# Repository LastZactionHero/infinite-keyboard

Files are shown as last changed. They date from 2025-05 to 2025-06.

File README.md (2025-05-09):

Infinite Keyboard is a portable musical scratchpad. It continously captures of every note played on the integrated keyboard as MIDI data, saved directly to an SD card. This allows you to freely play ideas as they occur, knowing they can always revisit the performance later. The system uses an ESP32-S3 microcontroller, with aPCM5102 DAC and TPA6130A2 headphone amplifier, and supports USB connectivity for potential MIDI output or other functions.

1. ESP32-S3 Module (ESP32-S3-WROOM-1-N8)
    [ ] Power (3.3V):
        [X] Connect module Pin 2 (3V3) to the main 3.3V power rail.
        [X] Connect module Pin 1 and Pin 40 (GND) and EPAD (Pin 41) to the main ground plane.
        [ ] Place bulk decoupling capacitor (10µF - 22µF) near the module between 3.3V and GND.
        [ ] Place local decoupling capacitor (0.1µF - 1µF) very close to Pin 2 (3V3) and GND.
    [X] Enable/Reset Circuit:
        [X] Connect an RC delay circuit to the EN pin (Pin 3): 10kΩ resistor to 3.3V, 1µF capacitor to GND.
        [X] Connect a momentary push button (Reset Switch) between EN (Pin 3) and GND.
    [X] Boot Mode Circuit:
        [X] Connect a 10kΩ pull-up resistor from GPIO0 (Pin 27) to 3.3V.
        [X] Connect a momentary push button (Boot Switch) between GPIO0 (Pin 27) and GND.
    [X] Crystal Oscillator: 40 MHz crystal is integrated within the module. No external crystal needed.
    [X] Antenna: Use onboard PCB antenna (WROOM-1). Ensure proper keep-out zones on your PCB as per layout guidelines. [cite: uploaded:esp32_s3_wroom_1_wroom_1u_datasheet_en-2930317.pdf]
2. USB Interface (Native OTG)
    [-] Connections:
        [X] Connect ESP32-S3 GPIO19 (Module Pin 13) to USB Connector D-.
        [X] Connect ESP32-S3 GPIO20 (Module Pin 14) to USB Connector D+.
        [X] Connect USB Connector VBUS to 5V supply (if host mode power required, consider power switching).
        [X] Connect USB Connector GND to main ground.
        [-] Connect USB Connector Shield to main ground.
    [-] Optional Components:
        [X] Place 0Ω series resistors/jumpers on D+/D- lines if desired.
        [-] Place ESD protection diodes (TVS array) near the connector on D+/D- lines.
    [] Layout: Route D+/D- as a 90Ω differential pair.
3. I2S Interface (ESP32-S3 to PCM5102)
    [X] Connections:
        [X] Connect ESP32-S3 GPIO (Select Pin) -> PCM5102 BCK (Pin 13).
        [X] Connect ESP32-S3 GPIO (Select Pin) -> PCM5102 LRCK (Pin 15).
        [X] Connect ESP32-S3 GPIO (Select Pin) -> PCM5102 DIN (Pin 14).
    [X] PCM5102 SCK: Ensure PCM5102 SCK (Pin 12) is connected to GND (to enable internal PLL). [cite: uploaded:pcm5102.pdf]
4. PCM5102 DAC Module
    [X] Power (3.3V):
        [X] Connect CPVDD (Pin 1), AVDD (Pin 8), DVDD (Pin 20) to 3.3V rail.
        [X] Connect CPGND (Pin 3), AGND (Pin 9), DGND (Pin 19) to ground plane (ensure proper analog/digital ground separation if needed, though often a single solid plane works well with careful layout).
        [X] Place 1µF decoupling capacitors close to pins 1, 8, 20 (to GND).
        [X] Place 1µF decoupling capacitor close to pin 18 (LDOO) (to DGND).
    [X] Charge Pump:
        [X] Connect 1µF ceramic capacitor between CAPP (Pin 2) and CAPM (Pin 4).
        [X] Connect 1µF ceramic capacitor from VNEG (Pin 5) to AGND.
    [X] Configuration Pins:
        [X] Connect FMT (Pin 16) to GND (I2S Format).
        [X] Connect FLT (Pin 11) to GND (Normal Latency Filter).
        [X] Connect DEMP (Pin 10) to GND (De-emphasis OFF).
        [X] Connect XSMT (Pin 17) to a selected ESP32-S3 GPIO pin for soft mute control.
    [X] Output Filter (Per Channel):
        [X] Connect 470Ω resistor in series with OUTL (Pin 6).
        [X] Connect 2.2nF capacitor from the output of the 470Ω resistor to AGND.
        [X] Repeat for OUTR (Pin 7).
5. I2C Interface (ESP32-S3 to TPA6130A2)
    [X] Connections:
        [X] Connect ESP32-S3 GPIO (Select SCL Pin) -> TPA6130A2 SCL (Pin 8 on QFN).
        [X] Connect ESP32-S3 GPIO (Select SDA Pin) -> TPA6130A2 SDA (Pin 7 on QFN).
    [X] Pull-up Resistors:
        [X] Connect 4.7kΩ pull-up resistor from SCL line to 3.3V rail.
        [X] Connect 4.7kΩ pull-up resistor from SDA line to 3.3V rail.
6. TPA6130A2 Headphone Amplifier Module
    [X] Power (5V):
        [X] Connect TPA6130A2 pins (e.g., Pin 12, Pin 20 on QFN) to 5V rail.
        [X] Connect TPA6130A2 GND pins (e.g., Pin 3, 9, 10, 13, 19 on QFN) and Thermal Pad (if QFN) to ground plane.
        [X] Place 1µF decoupling capacitors close to pins (to GND).
    [X] Charge Pump:
        [X] Connect 1µF low-ESR ceramic capacitor between CPP (Pin 18 on QFN) and CPN (Pin 17 on QFN).
        [X] Connect 1µF low-ESR ceramic capacitor from (Pin 15/16 on QFN) to GND.
    [X] Input Coupling (Single-Ended):
        [X] Connect PCM5102 Left Output (after filter) -> 0.47µF capacitor -> TPA6130A2 LEFTINM (Pin 1 on QFN).
        [X] Connect TPA6130A2 LEFTINP (Pin 2 on QFN) -> 0.47µF capacitor -> GND.
        [X] Connect PCM5102 Right Output (after filter) -> 0.47µF capacitor -> TPA6130A2 RIGHTINM (Pin 5 on QFN).
        [X] Connect TPA6130A2 RIGHTINP (Pin 4 on QFN) -> 0.47µF capacitor -> GND.
    [ ] Output:
        [X] Connect TPA6130A2 HPLEFT (Pin 14 on QFN) -> 3.5mm Jack Tip.
        [X] Connect TPA6130A2 HPRIGHT (Pin 11 on QFN) -> 3.5mm Jack Ring.
        [X] Connect 3.5mm Jack Sleeve -> GND.
    [X] Control Pins:
        [X] Connect SD (Shutdown) pin (Pin 6 on QFN) -> 10kΩ pull-up resistor -> 5V rail (Hardware Enabled).
7. SD Card Interface (SPI)
    [ ] Connections:
        [X] Connect ESP32-S3 GPIO (Select MOSI Pin) -> MicroSD Socket CMD (Pin 3).
        [X] Connect ESP32-S3 GPIO (Select MISO Pin) -> MicroSD Socket DAT0 (Pin 7).
        [X] Connect ESP32-S3 GPIO (Select SCK Pin) -> MicroSD Socket CLK (Pin 5).
        [X] Connect ESP32-S3 GPIO (Select CS Pin) -> MicroSD Socket DAT3/CS (Pin 2).
        [X] Connect MicroSD Socket VDD (Pin 4) -> 3.3V rail.
        [X] Connect MicroSD Socket VSS (Pin 6) -> GND.
    [ ] Supporting Components:
        [X] Place 0.1µF - 1µF decoupling capacitor near the socket VDD pin (to GND).
        [X] Connect 10kΩ - 50kΩ pull-up resistors from CS, MOSI, MISO, SCK lines to 3.3V rail.
    [ ] Optional: Connect Card Detect (CD) pin from socket (e.g., Pin Cd on MSD-1-A) to an ESP32-S3 GPIO if detection is desired. [cite: uploaded:msd_1_a-3510386.pdf]
8. User Interface
    [X] Keyboard Matrix (6x4):
        [X] Connect 6 Rows to 6 selected ESP32-S3 GPIOs.
        [X] Connect 4 Columns to 4 selected ESP32-S3 GPIOs.
        [X] Ensure diodes are included in the matrix design if required for ghosting prevention.
    [X] Push Buttons (x2):
        [X] Connect each button between a selected ESP32-S3 GPIO and GND.
        [X] Enable internal pull-up resistors on the ESP32-S3 GPIOs or add external pull-up resistors (e.g., 10kΩ to 3.3V).
    [X] LEDs (x2):
        [X] Connect each LED's anode to 3.3V (or other suitable supply).
        [X] Connect each LED's cathode through a current-limiting resistor (e.g., 220Ω - 1kΩ, value depends on LED specs and desired brightness) to a selected ESP32-S3 GPIO.
9. Power Supplies
    [ ] Input: Assume 5V input (e.g., from USB VBUS or external supply).
    [ ] 3.3V Regulator (LDO):
        [ ] Use MIC5504-3.3YM5-TR (SOT23-5 package).
        [ ] Connect LDO VIN pin to 5V input rail.
        [ ] Connect LDO GND pin to main ground plane.
        [ ] Connect LDO EN (Enable) pin to VIN (for always-on operation) or to an ESP32-S3 GPIO for software control.
        [ ] Connect LDO VOUT pin to the 3.3V power rail (supplying ESP32-S3, PCM5102, SD Card, UI pull-ups, etc.).
        [ ] Place input decoupling capacitor (e.g., 1µF ceramic) close to LDO VIN pin (to GND).
        [ ] Place output decoupling capacitor (e.g., 1µF ceramic) close to LDO VOUT pin (to GND). Check MIC5504 datasheet for specific capacitor requirements.
    [ ] 5V Rail: Ensure 5V rail is available for TPA6130A2 and LDO input.
    [ ] Layout: Employ good power supply layout practices (e.g., separate power planes or wide traces, proper decoupling placement).

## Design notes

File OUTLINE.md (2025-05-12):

**Project: Infinite Keyboard - Circuit Overview**

**Last Updated:** May 10, 2025 (Based on latest schematic review)

**1. Project Goal & Core Functionality:**
The "Infinite Keyboard" is a portable musical scratchpad. Its primary function is to continuously capture every note played on its integrated keyboard as MIDI data, saving this data directly to an SD card. This allows musicians to freely improvise and play ideas as they occur, with the assurance that the performance is recorded and can be revisited or exported later. The system includes headphone output for monitoring and USB connectivity for power and potential future MIDI output/data transfer.

**2. Key Components & Subsystems:**

*   **Microcontroller (MCU): ESP32-S3-WROOM-1-N8 (IC1)**
    *   Core of the system, responsible for:
        *   Scanning the keyboard matrix.
        *   Interpreting key presses into MIDI note data.
        *   Managing the SD card interface (SPI or SDIO mode) for writing MIDI files.
        *   Controlling the PCM5102A DAC via I²S for audio generation (likely for metronome/monitoring).
        *   Controlling the TPA6130A2 headphone amplifier via I²C (volume, mute, etc.).
        *   Driving status LEDs.
        *   Handling USB communication (power, potential MIDI I/O).
        *   Managing boot mode and user interface switches.
*   **Digital-to-Analog Converter (DAC): PCM5100APWR (IC3)**
    *   Receives I²S audio data from the ESP32.
    *   Converts digital audio to analog signals for headphone output.
    *   Operates in 3-wire I²S mode (using its internal PLL, SCK pin tied to GND).
    *   Configuration pins (FLT, FMT, DEMP) are tied to GND for normal latency FIR filter, I²S format, and de-emphasis off.
    *   XSMT (soft mute) pin is connected to the TPA6130A2 /SD (shutdown) pin, allowing coordinated mute/shutdown.
*   **Headphone Amplifier: TPA6130A2RTJR (IC4)**
    *   Amplifies the analog audio output from the PCM5102A.
    *   Drives the stereo headphone jack (J3).
    *   Features DirectPath™ technology for ground-referenced outputs (eliminates DC-blocking capacitors on output).
    *   Controlled via I²C by the ESP32.
    *   Powered by +5V.
*   **Linear Voltage Regulator (LDO): AP2112K-3.3TRG1 (IC5)**
    *   Takes +5V input (from USB VBUS).
    *   Provides a regulated +3.3V output rail for the ESP32, SD card, PCM5102A, and other 3.3V logic.
    *   Capacity: 600mA.
    *   Enable pin needs to be pulled high for operation.
*   **Keyboard Matrix:**
    *   24 keyswitches (SW1-SW24).
    *   Diode matrix (D1-D24, 1N4148WS) for N-key rollover and ghosting prevention.
    *   Scanned by ESP32 GPIOs (ROW1-6, COL1-4).
*   **Storage: Micro SD Card Slot (J2 - MSD-1-A)**
    *   Used for storing captured MIDI data.
    *   Interfaced with the ESP32.
    *   **Current plan is SPI mode (CLK, CMD/MOSI, DAT0/MISO, DAT3/CS).**
    *   Includes series termination resistors on actively driven lines and pull-up resistors on necessary signal lines.
    *   Mechanical card detect switch (CD1) connected to ESP32-IO35.
*   **User Interface:**
    *   Control Switches: BOOT1 (GPIO0), RESET1 (EN), MODE_A2 (GPIO45), MODE_B2 (GPIO46/GPIO3 - *pin assignment needs final confirmation*).
    *   Status LEDs: POWER1, RUNNING1, MODE_A1, MODE_B1. Anodes to +5V via 330Ω resistors, cathodes to ESP32 GPIOs.
*   **Connectors:**
    *   USB Type-C (J1 - UJ20-C-H-G-SMT-5-P16-TR): For power input (+5V) and potential USB data/MIDI. CC1/CC2 pins have 5.1kΩ pull-downs for UFP (device) mode.
    *   3.5mm Audio Jack (J3 - SJ-43617-SMT-TR): Stereo headphone output with tip, ring1, ring2, sleeve, and three detection switches (connected to ESP32 GPIOs).

**3. Power Distribution:**

*   **+5V Rail:** Derived from USB VBUS. Powers the TPA6130A2 headphone amplifier and is the input to the 3.3V LDO. Decoupled by C16, C19, C27.
*   **+3.3V Rail:** Generated by the AP2112K LDO (IC5) from the +5V rail. Powers the ESP32-S3, PCM5102A, SD card, and pull-up resistors for various logic signals. Extensively decoupled by C1, C3, C4, C5, C6, C7, C8, C9, C24, C25, C26, C28.

**4. Key Signal Paths & Interfaces:**

*   **Keyboard Data:** Switches -> Diode Matrix -> ESP32 GPIOs (Rows/Columns).
*   **SD Card Data (SPI Mode):** ESP32 SPI Pins <-> Series Resistors <-> J2 (SD Card).
    *   CLK, CMD (MOSI), DAT0 (MISO), DAT3 (CS) are the primary lines.
    *   Pull-ups on CMD, DAT0, DAT3, and recommended on unused DAT1, DAT2.
*   **Audio Path:**
    *   ESP32 (I²S: BCK, LRCK, DIN) -> PCM5102A (IC3).
    *   PCM5102A Analog Output (OUTL/R) -> RC Filters (R5/C14, R6/C15) ->
    *   AC Coupling Caps (C20-C23, 0.47µF) -> TPA6130A2 Analog Inputs (LEFTINP/M, RIGHTINP/M).
    *   TPA6130A2 Amplified Output (HPLEFT/HPRIGHT) -> J3 (Audio Jack).
*   **Control Interfaces:**
    *   ESP32 (I²C: SDA, SCL with R8/R9 pull-ups) -> TPA6130A2 (IC4).
    *   ESP32 GPIOs -> PCM5102A (XSMT), TPA6130A2 (/SD).
    *   ESP32 GPIOs -> LEDs.
    *   ESP32 GPIOs <- Switches (BOOT, RESET, MODE, Audio Jack Detect).
*   **USB Interface:** J1 (USB-C D+/D-) -> ESP32 (IO19/IO20).

**5. Important Design Considerations & Potential Review Points (for PCB stage):**

*   **LDO (IC5) Enable Pin:** The EN pin of the AP2112K LDO must be pulled high for the LDO to be active. This connection needs to be explicitly made.
*   **LDO (IC5) Pinout:** Ensure PCB footprint for IC5 matches the AP2112K pinout, as it differs from the previously considered MIC5504.
*   **SD Card Interface (SPI Mode):**
    *   Ensure DAT3 (CS) is correctly wired to an ESP32 GPIO, has a series termination resistor, and a pull-up resistor.
    *   Recommended to add pull-up resistors to +3.3V for the unused SD card lines DAT1 and DAT2 at the connector (J2) to prevent them from floating.
*   **Audio Jack Switch Pull-ups:** ESP32 GPIOs connected to the audio jack detection switches (J3 pins 10, 11, 12) should have external pull-up resistors or reliably enabled internal pull-ups to prevent floating inputs.
*   **ESP32 Strapping Pin GPIO3 (MODE_B1 LED / Switch):** If GPIO3 is indeed used for this dual purpose, ensure its boot-time state is reliably defined (e.g., via an external pull-up/down) considering its "floating" default state and connection to a switch.
*   **USB D+/D- Series Resistors:** Currently not present. Evaluate if needed based on trace length and desired USB robustness. (For FS, short traces might be okay).
*   **Decoupling Capacitor Placement:** Critical for all ICs. Must be as close as possible to power and ground pins.
*   **Grounding:** A solid ground plane is highly recommended. Pay attention to analog vs. digital ground separation/connection points, especially around the PCM5102A and TPA6130A2.
*   **Signal Routing:** Keep analog audio paths clean and isolated from digital noise. Route high-speed SD card and USB lines carefully.
*   **Thermal Management:** Provide adequate copper for heat dissipation for the LDO (IC5) and ESP32 (IC1).

**6. Bill of Materials (BOM) Notes:**

*   C24 value was updated to 1uF.
*   Resistors R20-R23 are 22Ω for SD card line termination. Additional resistors might be needed if 4-bit SD mode was chosen (but SPI is now confirmed).
*   Confirm all generic components (LEDs, Switches) have appropriate footprints selected.

This overview should provide a good foundation for evaluating the PCB layout. The critical items revolve around ensuring correct power delivery (LDO enable and pinout), robust SD card interfacing for the chosen SPI mode, and careful handling of sensitive analog signals and high-speed digital lines.

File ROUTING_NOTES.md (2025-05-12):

**I. General PCB Layout Best Practices:**

1.  **Component Placement First:**
    *   **Group Functional Blocks:** Place components that work together (e.g., ESP32 + its decoupling, LDO + its caps, DAC + its analog section, Amp + its I/O) close to each other.
    *   **Connectors:** Place connectors (USB-C, SD Card, Audio Jack) near the board edge where they will be accessed. Orient them logically.
    *   **User Interface:** Place switches (keyboard, control switches) and LEDs ergonomically.
    *   **Minimize Trace Lengths:** Shorter traces mean less noise pickup, less inductance, and better signal integrity, especially for high-speed signals.
    *   **Consider Thermal Management:** If the LDO (IC5 - AP2112K) or ESP32 is expected to dissipate significant heat, ensure adequate copper pour around them (connected to GND or a thermal plane if appropriate for the package) and potentially thermal vias if the package allows. The AP2112K in SOT-23-5 doesn't have a thermal pad, so a good ground plane connection and copper area is important.

2.  **Power Distribution Network (PDN):**
    *   **Solid Ground Plane:** Use a dedicated ground plane (e.g., a full layer on a multi-layer board, or a large, contiguous copper pour on a 2-layer board). This is crucial for signal integrity, noise reduction, and providing a low-impedance return path.
    *   **Power Planes/Traces:**
        *   Route power traces (+5V, +3.3V) as wide as practically possible to minimize voltage drop and impedance. Star distribution from the LDO output for +3.3V can be beneficial.
        *   Avoid long, thin power traces.
    *   **Decoupling Capacitors:**
        *   **Placement is KEY:** Place decoupling capacitors *as close as physically possible* to the power pins of each IC they are decoupling. The path from the cap to the IC power pin and then to the IC ground pin should be extremely short.
        *   **Via Placement:** If using vias to connect caps to power/ground planes, place vias close to the capacitor pads. Use multiple vias for lower impedance if needed, especially for bulk caps.
        *   **Hierarchy:** Typically, smaller value ceramic caps (0.1µF) handle high-frequency noise and should be closest. Larger bulk caps (1µF, 10µF) handle lower-frequency noise and transient current demands.

3.  **Signal Routing:**
    *   **Sensitive Signals:** Keep analog audio signals away from high-speed digital signals (SD card lines, USB, ESP32 clock/switching noise) and noisy power lines.
    *   **High-Speed Signals (SD Card, USB D+/D-):**
        *   Route these with controlled impedance if possible (though for shorter runs on a small board, careful routing might suffice).
        *   Keep them short and direct.
        *   Avoid stubs.
        *   Maintain consistent trace width.
        *   Route differential pairs (USB D+/D-) together, with matched lengths and consistent spacing.
    *   **Audio Signals (PCM5102A output, TPA6130A2 input/output):**
        *   Route as differential pairs if the DAC/Amp support it and your traces are long. For single-ended, ensure a clean, nearby ground return path.
        *   Keep left and right channel traces symmetrical if possible for balanced performance.
        *   Avoid routing them parallel to noisy digital lines for long distances. If they must cross, do so at 90 degrees.
        *   Consider guarding sensitive analog traces with ground traces or pours.
    *   **Clock Signals (SD_CLK, I2S_BCK, I2S_LRCK):** Treat these as high-frequency. Keep them short and away from sensitive analog lines.
    *   **No 90-Degree Bends:** Use 45-degree bends or curved traces instead of sharp 90-degree turns, especially for high-speed signals, to minimize reflections.
    *   **Return Paths:** Always consider the ground return path for every signal. A solid ground plane helps ensure short, low-impedance return paths. Avoid routing signals over splits or gaps in the ground plane.

4.  **Grounding Strategy:**
    *   **Single Point vs. Star Ground (for Analog/Digital):**
        *   For a mixed-signal board like this, if you have separate analog ground (AGND) and digital ground (DGND) sections (e.g., around the PCM5102A), they should be connected at a single point, typically at or very near the ADC/DAC.
        *   Alternatively, a very solid, unbroken main ground plane can often work well if component placement is managed to keep noisy digital currents away from sensitive analog areas.
    *   **Connector Grounds:** Ensure chassis grounds of connectors (USB shell, SD card shell, audio jack sleeve) are properly connected to the main ground plane, possibly via a ferrite bead or small resistor if EMI filtering is a concern (but for simplicity, direct connection is common).

**II. Component-Specific Routing Considerations:**

1.  **LDO (IC5 - AP2112K-3.3TRG1):**
    *   **Input/Output Capacitors (C27 for input; C28, C24, etc. for output):** Place these *extremely close* to the VIN/VOUT and GND pins of the LDO.
    *   **GND Connection:** Ensure a solid, low-impedance connection from the LDO's GND pin to the main ground plane.
    *   **Enable Pin (EN):** Route this cleanly. If tying high, connect it to VIN (Pin 5) with a short trace. (Confirm datasheet if direct tie is okay or if a pull-up resistor is preferred for the EN pin when tied high).

2.  **ESP32-S3-WROOM-1U (IC1):**
    *   **Decoupling (C4, C5, C6, C7, C8, C9, etc.):** Distribute these around the module, close to the various VDD3V3 and GND pins as per the ESP32 Hardware Design Guidelines.
    *   **Antenna (if using on-board for WROOM-1):** Follow keep-out zone recommendations from the datasheet. Ensure no copper (traces or planes) under or immediately around the antenna area.
    *   **SD Card Lines (CLK, CMD, DAT0-3):**
        *   Route these as a group. Keep them relatively short.
        *   Place series termination resistors (R20-R23, and potentially new ones for DAT2/3) *as close as possible* to the ESP32 pins.
    *   **USB D+/D-:** Route as a differential pair, matched length, controlled impedance if possible. Place any series resistors close to the ESP32.
    *   **I2S Lines (to PCM5102A):** Keep these short and direct.
    *   **Strapping Pins (GPIO0, GPIO3, GPIO45, GPIO46):** Ensure the components (switches, pull-ups/downs, capacitors to GND) are routed directly to these pins with short traces to avoid noise pickup during the critical boot-strapping phase.

3.  **PCM5102A DAC (IC3):**
    *   **Power Supplies (AVDD, DVDD, CPVDD):** Decouple each supply pin (pins 1, 8, 20) with its respective 0.1uF/1uF capacitors (C4, C5, C6, C8, C9 as per netlist allocation) *directly to their respective ground pins (AGND, DGND, CPGND)*.
    *   **Grounds (AGND, DGND, CPGND - pins 9, 19, 3):** The datasheet recommends connecting DGND and AGND together at the device. CPGND should also be connected to this common ground point. Ensure a clean, low-impedance connection.
    *   **Charge Pump Capacitors (C10, C11 for CAPM/CAPP/VNEG):** Place these very close to pins 2, 3, 4, 5.
    *   **LDOO Output (C12, C13):** Place these close to pin 18 (LDOO) and DGND.
    *   **Analog Outputs (OUTL, OUTR - pins 6, 7):** Route these traces symmetrically if possible. Keep them away from digital noise. These go to the RC filters (R5/C14, R6/C15). Place the filter components close to the DAC outputs.
    *   **SCK (Pin 12):** Ensure it's tied directly and shortly to GND.
    *   **FLT, FMT, DEMP (Pins 11, 16, 10):** Ensure they are tied directly and shortly to GND.

4.  **TPA6130A2 Headphone Amplifier (IC4):**
    *   **Power Supply (VDD_1, VDD_2 - pins 12, 20, both +5V):** Decouple with C16, C19 close to the IC, connected to a nearby GND pin or the ground plane.
    *   **Grounds (GND_1 to GND_5, Thermal Pad):** Ensure all ground pins and the thermal pad have solid connections to the main ground plane. Use multiple vias for the thermal pad if possible.
    *   **Input Coupling Capacitors (C20, C21, C22, C23 - 0.47uF):** Place these close to the input pins (LEFTINP/M, RIGHTINP/M - pins 1, 2, 4, 5).
    *   **Output Lines (HPLEFT, HPRIGHT - pins 14, 11):** Route these to the audio jack (J3). Keep them relatively short and direct. Maintain symmetry.
    *   **Charge Pump Capacitors (C18 for CPP/CPN; C17 for CPVSS):** Place C18 very close between pins 18 (CPP) and 17 (CPN). Place C17 close between pins 15/16 (CPVSS) and GND.
    *   **I2C Lines (SDA, SCL):** Route cleanly. Pull-up resistors R8, R9 can be placed closer to the ESP32 or the TPA6130A2, or midway.
    *   **/SD (Shutdown Pin 6):** Clean route from ESP32.

5.  **SD Card Connector (J2):**
    *   Place all associated components (series resistors, pull-up resistors, decoupling cap for its VDD pin) close to the connector or the ESP32 as appropriate for their function.
    *   Ensure a good ground connection for the shell/shield pins of the connector.

6.  **Audio Jack (J3):**
    *   Route output signals from TPA6130A2 directly.
    *   Ensure sleeve (GND) has a solid connection to the ground plane.
    *   Route switch lines (if used with pull-ups) cleanly to ESP32.

7.  **USB-C Connector (J1):**
    *   Route D+/D- as a differential pair from the ESP32.
    *   Ensure good grounding for the shell.
    *   Place CC1/CC2 pull-down resistors (R3, R4) close to the connector.
    *   Place VBUS decoupling (C27) close to the connector.

8.  **Keyboard Matrix (Switches SW1-SW24, Diodes D1-D24):**
    *   Routing will depend on the physical layout of keys.
    *   Ensure ROW and COLUMN traces are routed to minimize crosstalk if traces run parallel for long distances (though for a keyboard matrix, this is usually less critical than for high-speed data).
    *   Place diodes close to their respective switches.

**III. Manufacturing Considerations:**

*   **Trace Widths/Clearances:** Use appropriate trace widths for current carrying capacity (especially power traces) and adhere to your PCB manufacturer's minimum trace width/spacing capabilities.
*   **Via Sizes:** Use appropriate via sizes.
*   **Silkscreen:** Ensure clear labeling of components, test points, and connector orientations.
*   **Solder Mask:** Ensure proper solder mask openings for all SMT pads and any exposed copper areas (like thermal pads).

**Final Check before Sending to Fab:**

*   Run Design Rule Check (DRC) in your PCB software.
*   Double-check critical component footprints and pinouts against datasheets one last time.
*   Visually inspect routing for any obvious issues (acid traps, long stubs, signals crossing gaps in ground planes).

This is a lot, but being methodical during routing will save you a lot of headaches later! Good luck!

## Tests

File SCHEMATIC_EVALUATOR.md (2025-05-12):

Okay, I understand. Let's focus specifically on creating a thorough checklist for evaluating the **schematic** first. The goal is to build confidence in the design's electrical correctness based purely on the connections and component choices shown in the schematic, incorporating validation against datasheets.

Here is a list of key areas and specific checks crucial for evaluating a PCB schematic. If a schematic passes these checks (ideally verified against datasheets where applicable), you can be reasonably confident in its functional design before moving to the physical layout:

**Schematic Evaluation Checklist:**

1.  **Basic Connectivity & Electrical Rules:**
    * Are all component pins intended to be connected actually connected to a net? (Identifies unintentional open circuits).
    * Are there any nets with only one pin connection? (Could indicate a forgotten connection, unless it's an intentional test point or antenna connection).
    * Are power input pins connected to appropriate power nets?
    * Are ground pins connected to appropriate ground nets?
    * Are different power/ground domains (e.g., digital 3.3V, analog 3.3V, 5V, GND, AGND) correctly separated and/or connected via ferrite beads or other isolation methods if intended?
    * Are input pins correctly driven (not left floating unless specified as internal pull-up/down)?
    * Are output pins not directly shorted together (unless they are open-drain/collector with pull-ups)?

2.  **Component Selection and Usage:**
    * Does every component have a designated value or part number?
    * Are polarized components (electrolytic capacitors, diodes, ICs) shown with correct polarity/orientation?
    * Do component values seem appropriate for the circuit function (e.g., resistor values for pull-ups/downs, filter capacitors)?
    * Are components rated for the voltages and currents they will experience? (This is where datasheet comparison is vital).
    * Are required passive components (like series resistors, parallel resistors, filter capacitors) present on critical signal lines as per typical practice or datasheet recommendations?
    * Are component symbols correctly chosen to represent the intended physical part (especially pin mapping)?

3.  **Power Distribution & Decoupling:**
    * Are voltage regulator inputs and outputs correctly connected and bypassed with capacitors as per the datasheet recommendations?
    * Are decoupling capacitors present on the power pins of integrated circuits (especially digital logic, microcontrollers, and high-speed analog)?
    * Are the values and types of decoupling capacitors appropriate (e.g., smaller value ceramics for high-frequency decoupling close to pins, larger bulk capacitors on power rails)? (Datasheet recommendations are key here).
    * Is the power entry point protected (e.g., reverse polarity protection, input capacitance)?

4.  **Signal Integrity Considerations (Schematic Level):**
    * Are potential high-speed signal paths identifiable based on component types and net names?
    * Are recommended termination strategies shown for transmission lines (e.g., series resistors near drivers)? (Datasheet/application note comparison).
    * Are differential pairs correctly identified and wired?

5.  **Functional Blocks and Logic:**
    * Does the schematic clearly represent functional blocks?
    * Are the inputs and outputs between functional blocks correctly connected?
    * Are control signals correctly routed to the components they control?
    * Are unused pins on ICs handled according to datasheet recommendations (e.g., tied high, low, or left unconnected)?
    * Are necessary connectors, headers, and test points included?
    * Do connector pinouts match expected standards or mating parts?

6.  **Documentation and Readability:**
    * Is the schematic well-organized and easy to follow?
    * Are critical nets (power, ground, high-speed signals, control lines) clearly and consistently named?
    * Are there sufficient labels, notes, or comments to explain complex parts of the circuit?
    * Are hierarchical sheets (if used) logically structured and port connections clear?

This checklist provides a solid foundation for evaluating the schematic's correctness from an electrical design perspective.

Now, focusing *only* on getting the information needed to check these schematic points from the `.kicad_sch` file:

Given the types of schematic information required for this checklist (component designators, values/parts, footprints, pin numbers, net names, and the connections between pins and nets), what is the most suitable, information-dense format for extracting *only* this schematic data from KiCad for the LLM to consume?

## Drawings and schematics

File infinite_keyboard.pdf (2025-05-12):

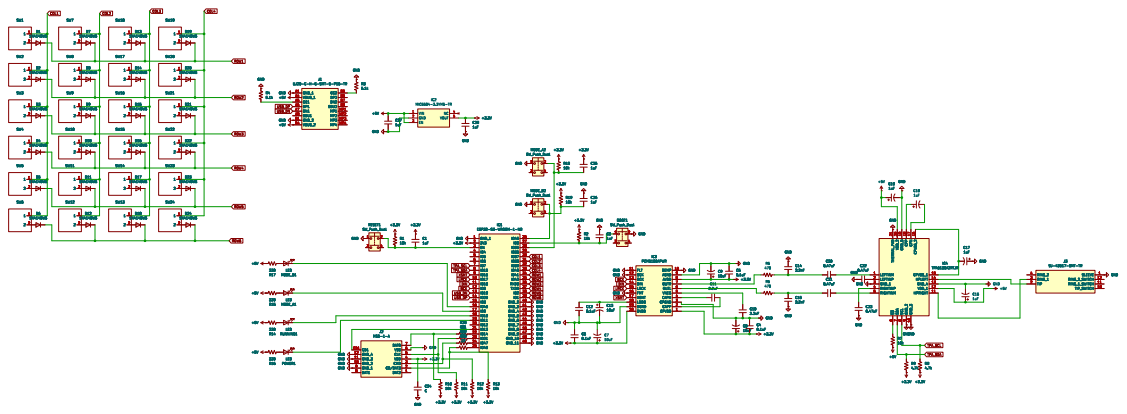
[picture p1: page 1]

Id: 1/1 Title: File: infinite_keyboard.kicad_sch Sheet: /

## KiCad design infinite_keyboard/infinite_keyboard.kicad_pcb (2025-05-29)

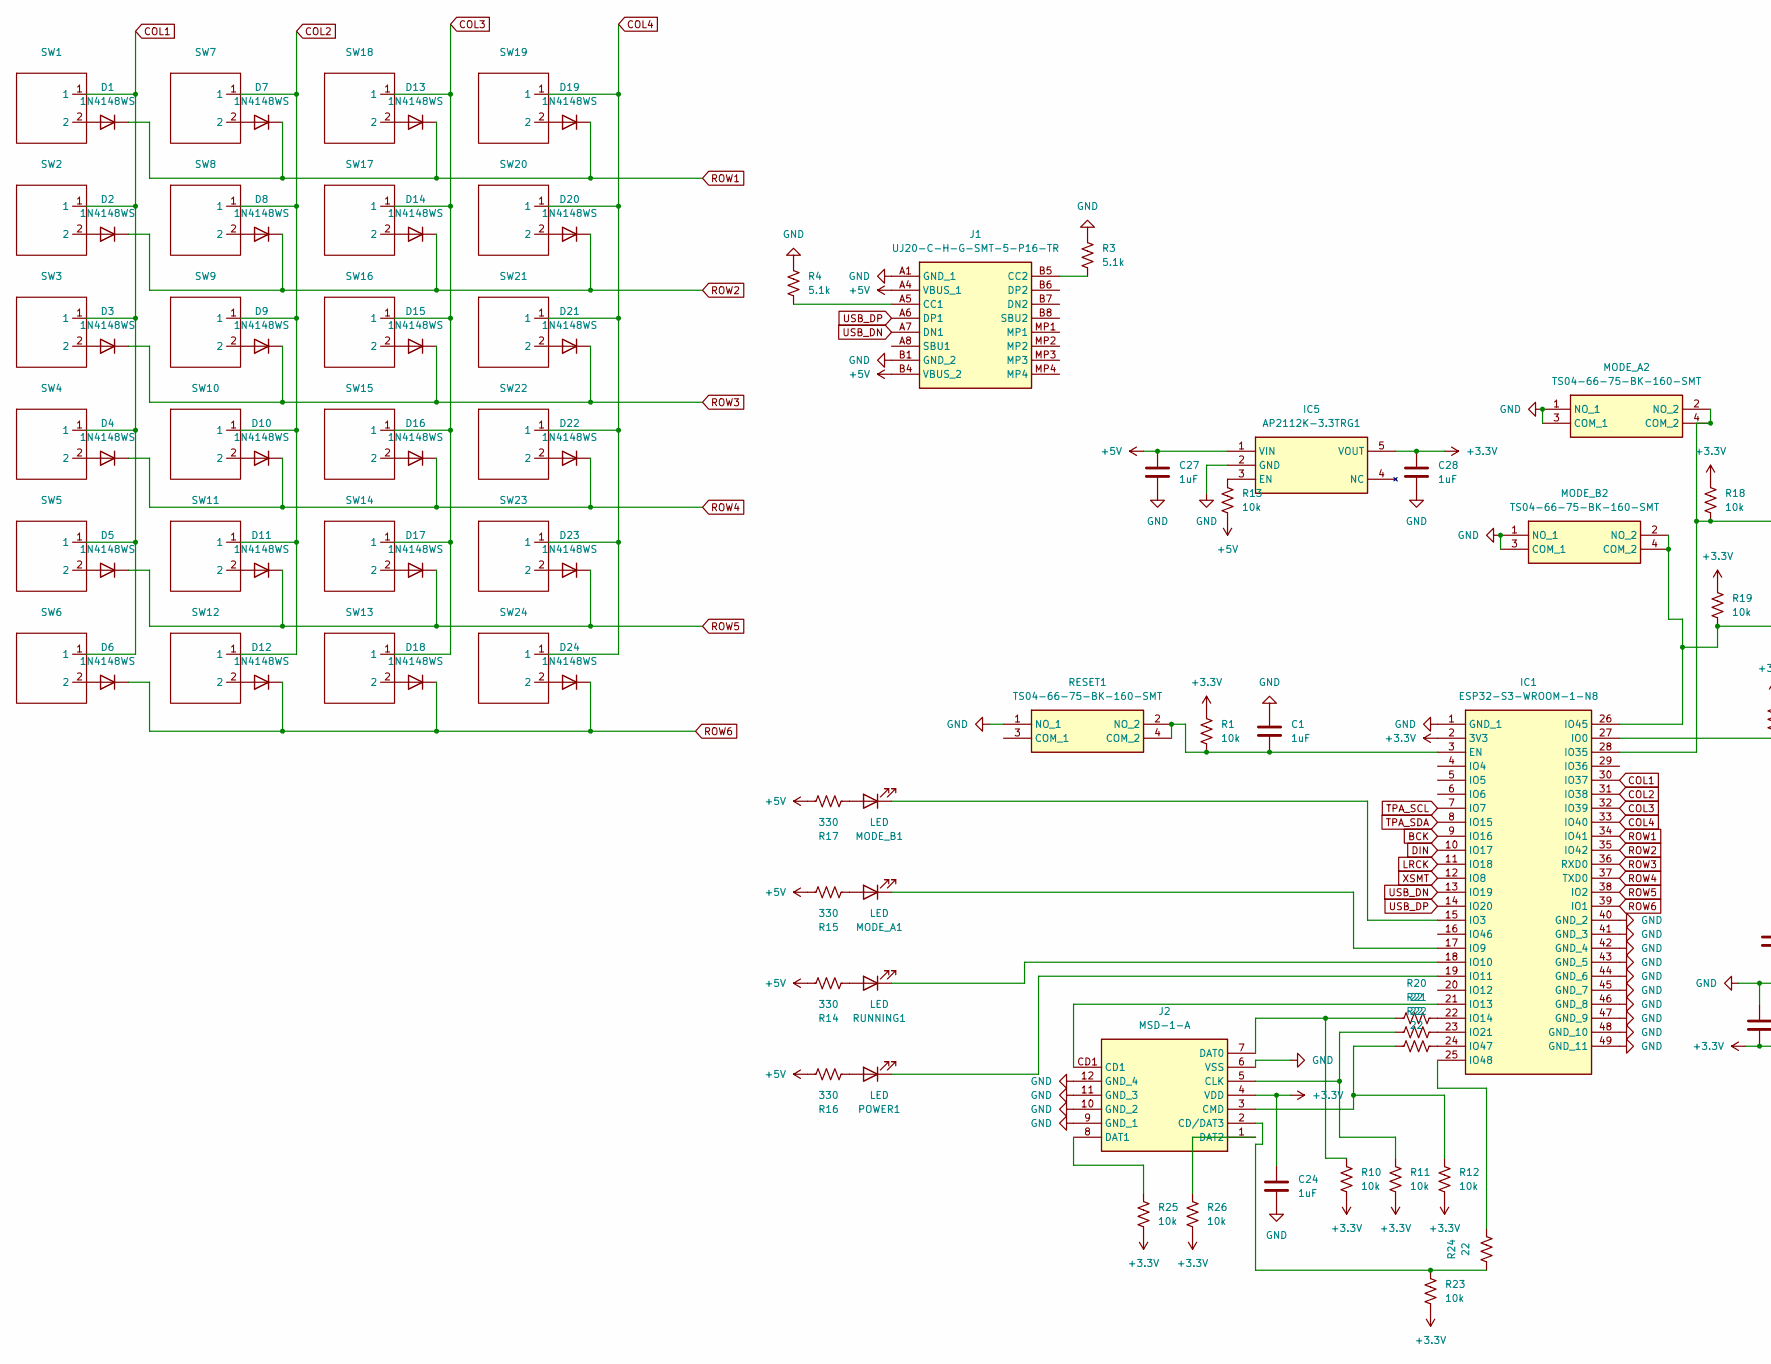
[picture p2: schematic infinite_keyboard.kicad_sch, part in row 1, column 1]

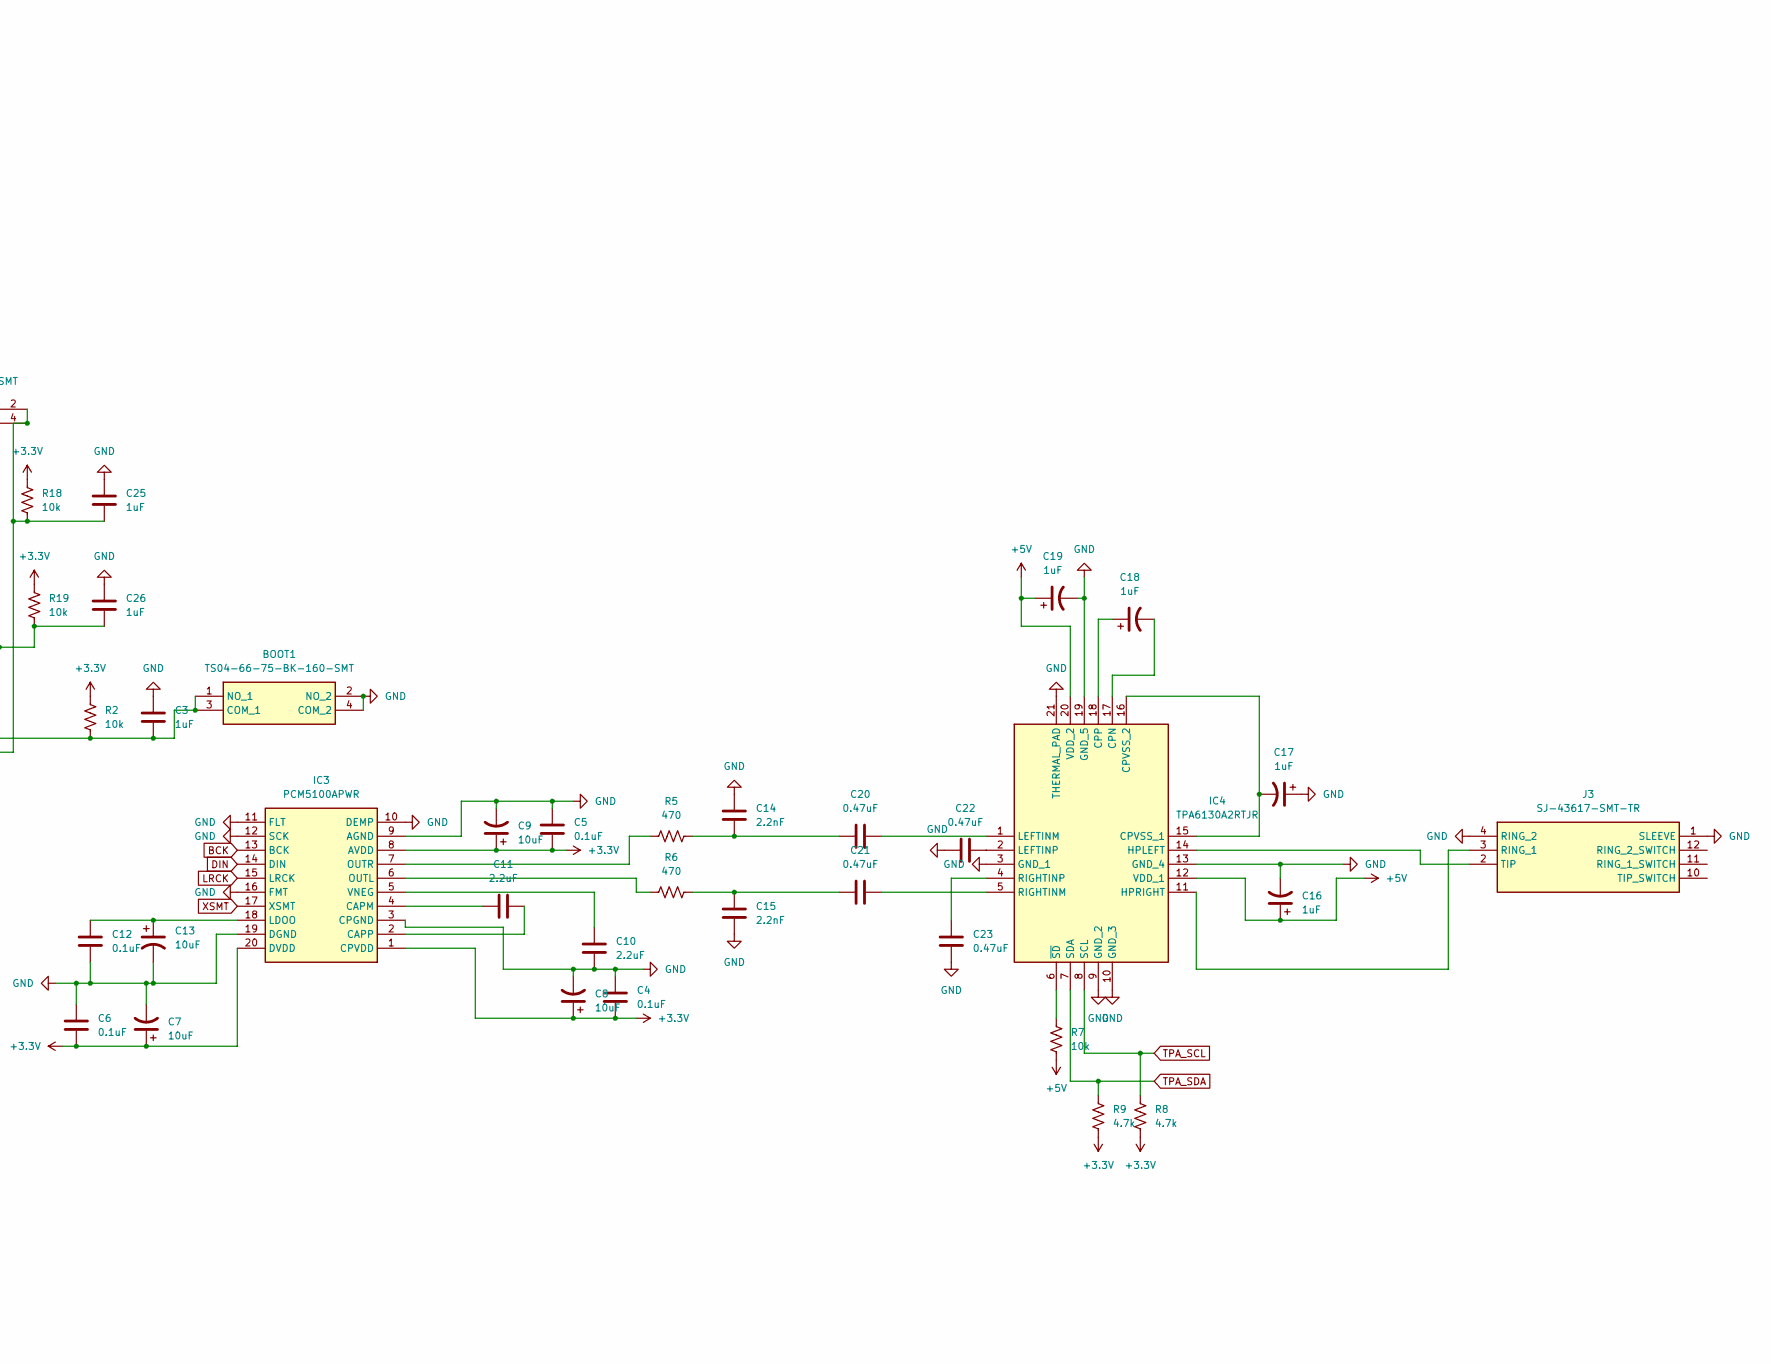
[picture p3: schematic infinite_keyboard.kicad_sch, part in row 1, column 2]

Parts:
BOOT1: TS04-66-75-BK-160-SMT; TS046675BK160SMT; Mouser Part Number 179-TS046675BK160SMT
C1, C3, C16, C17, C18, C19, C24, C25, C26, C27, C28: 1uF; C_0805_2012Metric
C4, C5, C6, C12: 0.1uF; C_0805_2012Metric
C7, C8, C9, C13: 10uF; C_0805_2012Metric
C10, C11: 2.2uF; C_0805_2012Metric
C14, C15: 2.2nF; C_0805_2012Metric
C20, C21, C22, C23: 0.47uF; C_0805_2012Metric
D1, D2, D3, D4, D5, D6, D7, D8, D9, D10, D11, D12, D13, D14, D15, D16, D17, D18, D19, D20, D21, D22, D23, D24: 1N4148WS; D_SOD-323F
IC1: ESP32-S3-WROOM-1-N8; ESP32S3WROOM1N8R2; Mouser Part Number 356-ESP32-S3WROOM1N8
IC3: PCM5100APWR; SOP65P640X120-20N; Mouser Part Number 595-PCM5100APWR
IC4: TPA6130A2RTJR; QFN50P400X400X80-21N-D; Mouser Part Number 595-TPA6130A2RTJR
IC5: AP2112K-3.3TRG1; SOT95P285X140-5N; Mouser Part Number 621-AP2112K-3.3TRG1
J1: UJ20-C-H-G-SMT-5-P16-TR; UJ20CHGSMT5P16TR; Mouser Part Number 179-UJ20CHGSMT5P16TR
J2: MSD-1-A; MSD1A; Mouser Part Number 179-MSD-1-A
J3: SJ-43617-SMT-TR; SJ43617SMTTR; Mouser Part Number 490-SJ-43617-SMT-TR
MODE_A1: LED; LED_0805_2012Metric
MODE_A2: TS04-66-75-BK-160-SMT; TS046675BK160SMT; Mouser Part Number 179-TS046675BK160SMT
MODE_B1: LED; LED_0805_2012Metric
MODE_B2: TS04-66-75-BK-160-SMT; TS046675BK160SMT; Mouser Part Number 179-TS046675BK160SMT
POWER1: LED; LED_0805_2012Metric
R1, R2, R7, R10, R11, R12, R13, R18, R19, R23, R25, R26: 10k; R_0805_2012Metric
R3, R4: 5.1k; R_0805_2012Metric
R5, R6: 470; R_0805_2012Metric
R8, R9: 4.7k; R_0805_2012Metric
R14, R15, R16, R17: 330; R_0805_2012Metric
R20, R21, R22, R24: 22; R_0805_2012Metric
RESET1: TS04-66-75-BK-160-SMT; TS046675BK160SMT; Mouser Part Number 179-TS046675BK160SMT
RUNNING1: LED; LED_0805_2012Metric
SW1, SW2, SW3, SW4, SW5, SW6, SW7, SW8, SW9, SW10, SW11, SW12, SW13, SW14, SW15, SW16, SW17, SW18, SW19, SW20, SW21, SW22, SW23, SW24: CherryMX_1.00u_PCB

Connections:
+3.3V: C4.2, C5.2, C6.2, C7.1, C8.1, C9.1, C24.1, C28.1, IC1.2 (3V3), IC3.1 (CPVDD), IC3.8 (AVDD), IC3.20 (DVDD), IC5.5 (VOUT), J2.4 (VDD), R1.1, R2.1, R8.2, R9.2, R10.2, R11.2, R12.2, R18.1, R19.1, R23.2, R25.2, R26.2
+5V: C16.1, C19.1, C27.1, IC4.12 (VDD_1), IC4.20 (VDD_2), IC5.1 (VIN), J1.A4 (VBUS_1), J1.B4 (VBUS_2), R7.2, R13.2, R14.2, R15.2, R16.2, R17.2
BCK: IC1.9 (IO16), IC3.13 (BCK)
COL1: IC1.30 (IO37), SW1.1, SW2.1, SW3.1, SW4.1, SW5.1, SW6.1
COL2: IC1.31 (IO38), SW7.1, SW8.1, SW9.1, SW10.1, SW11.1, SW12.1
COL3: IC1.32 (IO39), SW13.1, SW14.1, SW15.1, SW16.1, SW17.1, SW18.1
COL4: IC1.33 (IO40), SW19.1, SW20.1, SW21.1, SW22.1, SW23.1, SW24.1
DIN: IC1.10 (IO17), IC3.14 (DIN)
GND: BOOT1.2 (NO_2), BOOT1.4 (COM_2), C1.1, C3.1, C4.1, C5.1, C6.1, C7.2, C8.2, C9.2, C10.2, C12.2, C13.2, C14.1, C15.2, C16.2, C17.1, C19.2, C22.2, C23.2, C24.2, C25.1, C26.1, C27.2, C28.2, IC1.1 (GND_1), IC1.40 (GND_2), IC1.41 (GND_3), IC1.42 (GND_4), IC1.43 (GND_5), IC1.44 (GND_6), IC1.45 (GND_7), IC1.46 (GND_8), IC1.47 (GND_9), IC1.48 (GND_10), IC1.49 (GND_11), IC3.3 (CPGND), IC3.9 (AGND), IC3.10 (DEMP), IC3.11 (FLT), IC3.12 (SCK), IC3.16 (FMT), IC3.19 (DGND), IC4.3 (GND_1), IC4.9 (GND_2), IC4.10 (GND_3), IC4.13 (GND_4), IC4.19 (GND_5), IC4.21 (THERMAL_PAD), IC5.2 (GND), J1.A1 (GND_1), J1.B1 (GND_2), J2.6 (VSS), J2.9 (GND_1), J2.10 (GND_2), J2.11 (GND_3), J2.12 (GND_4), J3.1 (SLEEVE), J3.4 (RING_2), MODE_A2.1 (NO_1), MODE_A2.3 (COM_1), MODE_B2.1 (NO_1), MODE_B2.3 (COM_1), R3.1, R4.1, RESET1.1 (NO_1)
LRCK: IC1.11 (IO18), IC3.15 (LRCK)
unnamed: BOOT1.1 (NO_1), BOOT1.3 (COM_1), C3.2, IC1.27 (IO0), R2.2
unnamed: C14.2, C20.1, R5.2
unnamed: C15.1, C21.1, R6.2
unnamed: D1.2 (A), SW1.2
unnamed: D2.2 (A), SW2.2
unnamed: D3.2 (A), SW3.2
unnamed: D4.2 (A), SW4.2
unnamed: D5.2 (A), SW5.2
unnamed: D6.2 (A), SW6.2
unnamed: D7.2 (A), SW7.2
unnamed: D8.2 (A), SW8.2
unnamed: D9.2 (A), SW9.2
unnamed: D10.2 (A), SW10.2
unnamed: D11.2 (A), SW11.2
unnamed: D12.2 (A), SW12.2
unnamed: D13.2 (A), SW18.2
unnamed: D14.2 (A), SW17.2
unnamed: D15.2 (A), SW16.2
unnamed: D16.2 (A), SW15.2
unnamed: D17.2 (A), SW14.2
unnamed: D18.2 (A), SW13.2
unnamed: D19.2 (A), SW19.2
unnamed: D20.2 (A), SW20.2
unnamed: D21.2 (A), SW21.2
unnamed: D22.2 (A), SW22.2
unnamed: D23.2 (A), SW23.2
unnamed: D24.2 (A), SW24.2
unnamed: C1.2, IC1.3 (EN), R1.2, RESET1.2 (NO_2), RESET1.4 (COM_2)
unnamed: IC1.15 (IO3), MODE_B1.1 (K)
unnamed: IC1.17 (IO9), MODE_A1.1 (K)
unnamed: IC1.18 (IO10), RUNNING1.1 (K)
unnamed: IC1.19 (IO11), POWER1.1 (K)
unnamed: IC1.21 (IO13), J2.CD1
unnamed: IC1.22 (IO14), R20.2
unnamed: IC1.23 (IO21), R21.2
unnamed: C25.2, IC1.28 (IO35), MODE_A2.2 (NO_2), MODE_A2.4 (COM_2), R18.2
unnamed: C26.2, IC1.26 (IO45), MODE_B2.2 (NO_2), MODE_B2.4 (COM_2), R19.2
unnamed: IC1.24 (IO47), R22.2
unnamed: IC1.25 (IO48), R24.2
unnamed: C11.1, IC3.4 (CAPM)
unnamed: C11.2, IC3.2 (CAPP)
unnamed: C12.1, C13.1, IC3.18 (LDOO)
unnamed: IC3.6 (OUTL), R6.1
unnamed: IC3.7 (OUTR), R5.1
unnamed: C10.1, IC3.5 (VNEG)
unnamed: C18.2, IC4.17 (CPN)
unnamed: C18.1, IC4.18 (CPP)
unnamed: C17.2, IC4.15 (CPVSS_1), IC4.16 (CPVSS_2)
unnamed: IC4.14 (HPLEFT), J3.2 (TIP)
unnamed: IC4.11 (HPRIGHT), J3.3 (RING_1)
unnamed: C20.2, IC4.1 (LEFTINM)
unnamed: C22.1, IC4.2 (LEFTINP)
unnamed: C21.2, IC4.5 (RIGHTINM)
unnamed: C23.1, IC4.4 (RIGHTINP)
unnamed: IC4.6 (~SD), R7.1
unnamed: IC5.3 (EN), R13.1
unnamed: J1.A5 (CC1), R4.2
unnamed: J1.B5 (CC2), R3.2
unnamed: J2.2 (CD/DAT3), R23.1, R24.1
unnamed: J2.5 (CLK), R11.1, R21.1
unnamed: J2.3 (CMD), R12.1, R22.1
unnamed: J2.7 (DAT0), R10.1, R20.1
unnamed: J2.8 (DAT1), R25.1
unnamed: J2.1 (DAT2), R26.1
unnamed: MODE_A1.2 (A), R15.1
unnamed: MODE_B1.2 (A), R17.1
unnamed: POWER1.2 (A), R16.1
unnamed: R14.1, RUNNING1.2 (A)
ROW1: D1.1 (K), D7.1 (K), D13.1 (K), D19.1 (K), IC1.34 (IO41)
ROW2: D2.1 (K), D8.1 (K), D14.1 (K), D20.1 (K), IC1.35 (IO42)
ROW3: D3.1 (K), D9.1 (K), D15.1 (K), D21.1 (K), IC1.36 (RXD0)
ROW4: D4.1 (K), D10.1 (K), D16.1 (K), D22.1 (K), IC1.37 (TXD0)
ROW5: D5.1 (K), D11.1 (K), D17.1 (K), D23.1 (K), IC1.38 (IO2)
ROW6: D6.1 (K), D12.1 (K), D18.1 (K), D24.1 (K), IC1.39 (IO1)
TPA_SCL: IC1.7 (IO7), IC4.8 (SCL), R8.1
TPA_SDA: IC1.8 (IO15), IC4.7 (SDA), R9.1
USB_DN: IC1.13 (IO19), J1.A7 (DN1)
USB_DP: IC1.14 (IO20), J1.A6 (DP1)
XSMT: IC1.12 (IO8), IC3.17 (XSMT)

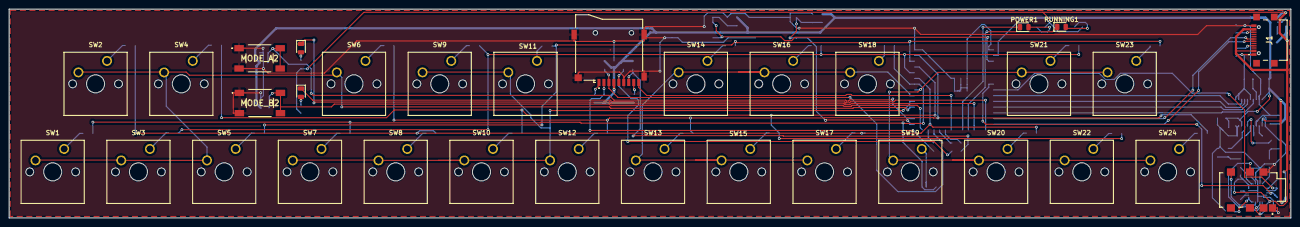
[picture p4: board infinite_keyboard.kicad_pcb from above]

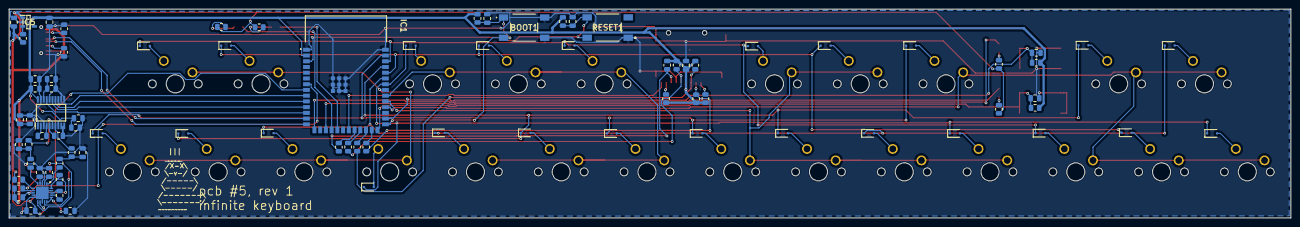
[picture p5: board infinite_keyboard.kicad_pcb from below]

Board: 2 copper layers, 283.9 x 46.2 mm, 116 parts (83 on the bottom side), 89 nets.

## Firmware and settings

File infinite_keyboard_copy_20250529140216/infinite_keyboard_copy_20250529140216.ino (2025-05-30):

#include <Arduino.h>
#include "driver/i2s.h" // For I2S audio output
#include <Wire.h>       // For I2C communication with the amplifier

// --- Keyboard Matrix Definitions ---
const int NUM_ROWS = 6;
const int NUM_COLS = 4;
const int NUM_TOTAL_SWITCHES = NUM_ROWS * NUM_COLS; // 24 switches

// Define the GPIO pins for columns (outputs)
const int colPins[NUM_COLS] = {
  37, // COL 1: IO37
  38, // COL 2: IO38
  39, // COL 3: IO39
  40  // COL 4: IO40
};

// Define the GPIO pins for rows (inputs with pull-downs)
const int rowPins[NUM_ROWS] = {
  41, // ROW 1: IO41
  42, // ROW 2: IO42
  44, // ROW 3: RXD0 (GPIO44)
  43, // ROW 4: TXD0 (GPIO43)
  2,  // ROW 5: IO2
  1   // ROW 6: IO1
};

// --- Switch Enum Definition ---
typedef enum {
  SW_INVALID = 0, // Represents an unmapped or invalid switch
  SW1, SW2, SW3, SW4, SW5, SW6,
  SW7, SW8, SW9, SW10, SW11, SW12,
  SW13, SW14, SW15, SW16, SW17, SW18,
  SW19, SW20, SW21, SW22, SW23, SW24
} SwitchID_t;

// --- Note Enum Definition ---
typedef enum {
  NOTE_NONE = 0, 
  C4_N, Db4_N, D4_N, Eb4_N, E4_N, F4_N, Gb4_N, G4_N, Ab4_N, A4_N, Bb4_N, B4_N,
  C5_N, Db5_N, D5_N, Eb5_N, E5_N, F5_N, Gb5_N, G5_N, Ab5_N, A5_N, Bb5_N, B5_N,
  NOTE_COUNT 
} Note_t;

// --- Audio Definitions ---
#define I2S_BCK_PIN   16 // Bit Clock
#define I2S_LRCK_PIN  18 // Left/Right Clock (Word Select)
#define I2S_DIN_PIN   17 // Data Out

#define PCM_XSMT_PIN  8  // Soft Mute for DAC (HIGH = un-muted)

#define TPA_SCL_PIN   7  // I2C Clock for TPA6130A2 Amplifier
#define TPA_SDA_PIN   15 // I2C Data for TPA6130A2 Amplifier
#define TPA6130A2_ADDR 0x60 // TPA6130A2 I2C Address (ADDR pin LOW)

#define SAMPLE_RATE         44100
#define BITS_PER_SAMPLE     I2S_BITS_PER_SAMPLE_16BIT
#define NUM_AUDIO_CHANNELS  I2S_CHANNEL_FMT_RIGHT_LEFT // Stereo
#define VOLUME_PERCENTAGE   0.05f  // Adjust as needed
#define MAX_POLYPHONY       5      // Maximum number of simultaneous notes
#define MAX_AMPLITUDE       32767.0f  // Maximum 16-bit amplitude

#define I2S_BUFFER_SIZE 256 
int16_t i2s_buffer[I2S_BUFFER_SIZE * 2]; 

float currentPlayingFrequency = 0.0f; 
float phase = 0.0;


// --- Keyboard State Variables & Mappings ---
SwitchID_t physicalKeyToSwitchID[NUM_ROWS][NUM_COLS];
bool currentSwitchIsPressed[NUM_TOTAL_SWITCHES + 1];
Note_t switchNoteAssignment[NUM_TOTAL_SWITCHES + 1];
const char* noteEnumToStringMap[NOTE_COUNT];
float noteEnumToFrequencyMap[NOTE_COUNT];

// Structure to hold active note information
struct ActiveNote {
  float frequency;
  Note_t note;
  bool isActive;
  float phase;
  float modulatorPhase;  // For FM synthesis
};

ActiveNote activeNotes[MAX_POLYPHONY];
int numActiveNotes = 0;

// --- TPA6130A2 Amplifier Control ---
void set_tpa6130a2_register(uint8_t reg, uint8_t value) {
  Wire.beginTransmission(TPA6130A2_ADDR);
  Wire.write(reg);
  Wire.write(value);
  byte error = Wire.endTransmission();
  if (error != 0) {
    Serial.print("Error writing to TPA6130A2 register 0x");
    Serial.print(reg, HEX); Serial.print(": Error code "); Serial.println(error);
  }
}

void setup_tpa6130a2() {
  Serial.println("Configuring TPA6130A2 Headphone Amplifier...");
  set_tpa6130a2_register(0x01, 0xC0); // Enable L/R, Stereo
  delay(10); 
  set_tpa6130a2_register(0x02, 0x1C); // Unmute L/R, Volume 0dB
  Serial.println("TPA6130A2 configuration complete.");
}

// --- I2S Setup ---
void setup_i2s() {
  Serial.println("Configuring I2S interface...");
  i2s_config_t i2s_config = {
    .mode = (i2s_mode_t)(I2S_MODE_MASTER | I2S_MODE_TX),
    .sample_rate = SAMPLE_RATE,
    .bits_per_sample = BITS_PER_SAMPLE,
    .channel_format = NUM_AUDIO_CHANNELS,
    .communication_format = I2S_COMM_FORMAT_STAND_I2S,
    .intr_alloc_flags = ESP_INTR_FLAG_LEVEL1,
    .dma_buf_count = 8,
    .dma_buf_len = 64, 
    .use_apll = true,
    .tx_desc_auto_clear = true,
    .fixed_mclk = 0
  };
  i2s_pin_config_t pin_config = {
    .bck_io_num = I2S_BCK_PIN,
    .ws_io_num = I2S_LRCK_PIN,
    .data_out_num = I2S_DIN_PIN,
    .data_in_num = I2S_PIN_NO_CHANGE
  };
  if (i2s_driver_install(I2S_NUM_0, &i2s_config, 0, NULL) != ESP_OK) {
    Serial.println("I2S driver install failed"); return;
  }
  if (i2s_set_pin(I2S_NUM_0, &pin_config) != ESP_OK) {
    Serial.println("I2S set pin failed"); return;
  }
  if (i2s_set_clk(I2S_NUM_0, SAMPLE_RATE, BITS_PER_SAMPLE, I2S_CHANNEL_STEREO) != ESP_OK) {
    Serial.println("I2S set clock failed"); return;
  }
  Serial.println("I2S interface configured.");
}


// --- Mapping Setup Functions ---
void setupSwitchMapping() {
  Serial.println("Mapping physical keys to SwitchID enums (manual assignment)...");
  for (int r_init = 0; r_init < NUM_ROWS; r_init++) {
    for (int c_init = 0; c_init < NUM_COLS; c_init++) {
      physicalKeyToSwitchID[r_init][c_init] = SW_INVALID;
    }
  }
  physicalKeyToSwitchID[0][0] = SW1; physicalKeyToSwitchID[1][0] = SW2; physicalKeyToSwitchID[2][0] = SW3;
  physicalKeyToSwitchID[3][0] = SW4; physicalKeyToSwitchID[4][0] = SW5; physicalKeyToSwitchID[5][0] = SW6;
  physicalKeyToSwitchID[0][1] = SW7; physicalKeyToSwitchID[1][1] = SW8; physicalKeyToSwitchID[2][1] = SW9;
  physicalKeyToSwitchID[3][1] = SW10; physicalKeyToSwitchID[4][1] = SW11; physicalKeyToSwitchID[5][1] = SW12;
  physicalKeyToSwitchID[0][2] = SW18; physicalKeyToSwitchID[1][2] = SW17; physicalKeyToSwitchID[2][2] = SW16;
  physicalKeyToSwitchID[3][2] = SW15; physicalKeyToSwitchID[4][2] = SW14; physicalKeyToSwitchID[5][2] = SW13;
  physicalKeyToSwitchID[0][3] = SW19; physicalKeyToSwitchID[1][3] = SW20; physicalKeyToSwitchID[2][3] = SW21;
  physicalKeyToSwitchID[3][3] = SW22; physicalKeyToSwitchID[4][3] = SW23; physicalKeyToSwitchID[5][3] = SW24;

  Serial.println("VERIFY: Current physical key to Switch ID mapping:");
  for (int r_verify = 0; r_verify < NUM_ROWS; r_verify++) {
    String rowString = "  Row " + String(r_verify) + ": ";
    for (int c_verify = 0; c_verify < NUM_COLS; c_verify++) {
      SwitchID_t sw = physicalKeyToSwitchID[r_verify][c_verify];
      rowString += "C" + String(c_verify) + "=" + (sw != SW_INVALID ? "SW" + String(static_cast<int>(sw)) : "N/A") + "   ";
    }
    Serial.println(rowString);
  }
}

void initializeNoteStrings() {
  Serial.println("Initializing Note Enum to String map...");
  for(int i=0; i < NOTE_COUNT; ++i) noteEnumToStringMap[i] = "N/A";
  noteEnumToStringMap[C4_N] = "C4"; noteEnumToStringMap[Db4_N] = "Db4"; noteEnumToStringMap[D4_N] = "D4";
  noteEnumToStringMap[Eb4_N] = "Eb4"; noteEnumToStringMap[E4_N] = "E4"; noteEnumToStringMap[F4_N] = "F4";
  noteEnumToStringMap[Gb4_N] = "Gb4"; noteEnumToStringMap[G4_N] = "G4"; noteEnumToStringMap[Ab4_N] = "Ab4";
  noteEnumToStringMap[A4_N] = "A4"; noteEnumToStringMap[Bb4_N] = "Bb4"; noteEnumToStringMap[B4_N] = "B4";
  noteEnumToStringMap[C5_N] = "C5"; noteEnumToStringMap[Db5_N] = "Db5"; noteEnumToStringMap[D5_N] = "D5";
  noteEnumToStringMap[Eb5_N] = "Eb5"; noteEnumToStringMap[E5_N] = "E5"; noteEnumToStringMap[F5_N] = "F5";
  noteEnumToStringMap[Gb5_N] = "Gb5"; noteEnumToStringMap[G5_N] = "G5"; noteEnumToStringMap[Ab5_N] = "Ab5";
  noteEnumToStringMap[A5_N] = "A5"; noteEnumToStringMap[Bb5_N] = "Bb5"; noteEnumToStringMap[B5_N] = "B5";
  
  Serial.println("VERIFY: Note Enum to String mapping:");
  for (int i = 1; i < NOTE_COUNT; i++) {
      Serial.print("  NoteEnumVal "); Serial.print(i); Serial.print(" (");
      Serial.print(noteEnumToStringMap[static_cast<Note_t>(i)]); Serial.println(")");
  }
}

void setupNoteMapping() {
  Serial.println("Mapping SwitchIDs to Note_t enums (manual assignment)...");
  for (int i = 0; i <= NUM_TOTAL_SWITCHES; i++) switchNoteAssignment[i] = NOTE_NONE;
  switchNoteAssignment[static_cast<int>(SW1)] = C4_N; switchNoteAssignment[static_cast<int>(SW2)] = Db4_N;
  switchNoteAssignment[static_cast<int>(SW3)] = D4_N; switchNoteAssignment[static_cast<int>(SW4)] = Eb4_N;
  switchNoteAssignment[static_cast<int>(SW5)] = E4_N; switchNoteAssignment[static_cast<int>(SW6)] = Gb4_N; 
  switchNoteAssignment[static_cast<int>(SW7)] = F4_N; switchNoteAssignment[static_cast<int>(SW8)] = G4_N;
  switchNoteAssignment[static_cast<int>(SW9)] = Ab4_N; switchNoteAssignment[static_cast<int>(SW10)] = A4_N;
  switchNoteAssignment[static_cast<int>(SW11)] = Bb4_N; switchNoteAssignment[static_cast<int>(SW12)] = B4_N;
  switchNoteAssignment[static_cast<int>(SW13)] = C5_N; switchNoteAssignment[static_cast<int>(SW14)] = Db5_N;
  switchNoteAssignment[static_cast<int>(SW15)] = D5_N; switchNoteAssignment[static_cast<int>(SW16)] = Eb5_N;
  switchNoteAssignment[static_cast<int>(SW17)] = E5_N; switchNoteAssignment[static_cast<int>(SW18)] = Gb5_N; 
  switchNoteAssignment[static_cast<int>(SW19)] = F5_N; switchNoteAssignment[static_cast<int>(SW20)] = G5_N;
  switchNoteAssignment[static_cast<int>(SW21)] = Ab5_N; switchNoteAssignment[static_cast<int>(SW22)] = A5_N;
  switchNoteAssignment[static_cast<int>(SW23)] = Bb5_N; switchNoteAssignment[static_cast<int>(SW24)] = B5_N;

  Serial.println("VERIFY: Current Switch ID to Note_t enum mapping:");
  for (int i = 1; i <= NUM_TOTAL_SWITCHES; i++) {
    Serial.print("  SW"); Serial.print(i); Serial.print(" -> NoteEnumVal: "); Serial.print(static_cast<int>(switchNoteAssignment[i]));
    Serial.print(" (String: "); Serial.print(noteEnumToStringMap[switchNoteAssignment[i]]); Serial.println(")");
  }
}

void initializeNoteFrequencies() {
  Serial.println("Initializing Note Enum to Frequency map...");
  for(int i=0; i < NOTE_COUNT; ++i) noteEnumToFrequencyMap[i] = 0.0f;
  noteEnumToFrequencyMap[C4_N]  = 261.63f; noteEnumToFrequencyMap[Db4_N] = 277.18f; noteEnumToFrequencyMap[D4_N]  = 293.66f;
  noteEnumToFrequencyMap[Eb4_N] = 311.13f; noteEnumToFrequencyMap[E4_N]  = 329.63f; noteEnumToFrequencyMap[F4_N]  = 349.23f;
  noteEnumToFrequencyMap[Gb4_N] = 369.99f; noteEnumToFrequencyMap[G4_N]  = 392.00f; noteEnumToFrequencyMap[Ab4_N] = 415.30f;
  noteEnumToFrequencyMap[A4_N]  = 440.00f; noteEnumToFrequencyMap[Bb4_N] = 466.16f; noteEnumToFrequencyMap[B4_N]  = 493.88f;
  noteEnumToFrequencyMap[C5_N]  = 523.25f; noteEnumToFrequencyMap[Db5_N] = 554.37f; noteEnumToFrequencyMap[D5_N]  = 587.33f;
  noteEnumToFrequencyMap[Eb5_N] = 622.25f; noteEnumToFrequencyMap[E5_N]  = 659.25f; noteEnumToFrequencyMap[F5_N]  = 698.46f;
  noteEnumToFrequencyMap[Gb5_N] = 739.99f; noteEnumToFrequencyMap[G5_N]  = 783.99f; noteEnumToFrequencyMap[Ab5_N] = 830.61f;
  noteEnumToFrequencyMap[A5_N]  = 880.00f; noteEnumToFrequencyMap[Bb5_N] = 932.33f; noteEnumToFrequencyMap[B5_N]  = 987.77f;

  Serial.println("VERIFY: Note Enum to Frequency mapping:");
  for (int i = 1; i < NOTE_COUNT; i++) {
      Serial.print("  NoteEnumVal "); Serial.print(i); Serial.print(" (");
      Serial.print(noteEnumToStringMap[static_cast<Note_t>(i)]);
      Serial.print("): Freq "); Serial.println(noteEnumToFrequencyMap[static_cast<Note_t>(i)], 2);
  }
}

// --- Synth Type Definitions ---
typedef enum {
  SYNTH_SINE,
  SYNTH_SAW,
  SYNTH_SQUARE,
  SYNTH_FM,
  // Future synth types will be added here
} SynthType_t;

// Set default synth type at compile time
#define DEFAULT_SYNTH_TYPE SYNTH_FM

// Base class for all synth types
class Synth {
protected:
  float frequency;
  float phase;
  float volume;

public:
  Synth() : frequency(0.0f), phase(0.0f), volume(0.15f) {}
  virtual ~Synth() {}
  
  virtual void setFrequency(float freq) {
    frequency = freq;
    if (freq == 0.0f) {
      phase = 0.0f;
    }
  }
  
  void setVolume(float vol) {
    volume = vol;
  }
  
  virtual float generateSample(float notePhase, float& modPhase) {
    return generateSample(notePhase); // Default implementation for non-FM synths
  }
  
  virtual float generateSample(float notePhase) {
    if (frequency <= 0.0f) return 0.0f;
    return sin(notePhase) * volume;
  }
};

// Sine wave implementation
class SineSynth : public Synth {
public:
  float generateSample(float notePhase) override {
    if (frequency <= 0.0f) return 0.0f;
    return sin(notePhase) * volume;
  }
};

// Sawtooth wave implementation
class SawSynth : public Synth {
public:
  float generateSample(float notePhase) override {
    if (frequency <= 0.0f) return 0.0f;
    return ((notePhase / TWO_PI) * 2.0f - 1.0f) * volume;
  }
};

// Square wave implementation
class SquareSynth : public Synth {
public:
  float generateSample(float notePhase) override {
    if (frequency <= 0.0f) return 0.0f;
    return (notePhase < PI ? 1.0f : -1.0f) * volume;
  }
};

// FM synthesis implementation
class FMSynth : public Synth {
private:
  float modulationIndex;
  float modulatorRatio;
  
public:
  FMSynth() : Synth(), modulationIndex(2.0f), modulatorRatio(2.0f) {}
  
  float generateSample(float notePhase, float& modPhase) override {
    if (frequency <= 0.0f) return 0.0f;
    
    // Calculate modulator frequency based on ratio
    float modulatorFreq = frequency * modulatorRatio;
    
    // Generate modulator signal
    float modulatorSignal = sin(modPhase);
    
    // Apply modulation to carrier phase
    float modulatedPhase = notePhase + (modulatorSignal * modulationIndex);
    
    // Generate carrier signal with modulated phase
    float sample = sin(modulatedPhase) * volume;
    
    // Update modulator phase
    modPhase += (TWO_PI * modulatorFreq) / SAMPLE_RATE;
    if (modPhase >= TWO_PI) {
      modPhase -= TWO_PI;
    }
    
    return sample;
  }
};

// Global synth instance
Synth* currentSynth = nullptr;

// --- Main Setup ---
void setup() {
  Serial.begin(115200);
  delay(1000); 
  Serial.println("ESP32-S3 Keyboard Synthesizer Initialized");

  // Initialize keyboard column pins
  for (int i = 0; i < NUM_COLS; i++) {
    pinMode(colPins[i], OUTPUT);
    digitalWrite(colPins[i], LOW);
  }
  // Initialize keyboard row pins
  for (int i = 0; i < NUM_ROWS; i++) {
    pinMode(rowPins[i], INPUT_PULLDOWN);
  }

  // Initialize Mappings
  initializeNoteStrings();     
  initializeNoteFrequencies(); 
  setupSwitchMapping();        
  setupNoteMapping();          

  // Initialize switch states
  for (int i = 0; i <= NUM_TOTAL_SWITCHES; i++) {
    currentSwitchIsPressed[i] = false;
  }

  // Configure DAC Mute Pin
  pinMode(PCM_XSMT_PIN, OUTPUT);
  digitalWrite(PCM_XSMT_PIN, HIGH); // Un-mute the DAC
  Serial.println("PCM5100A XSMT pin set HIGH (un-muted).");

  // Initialize I2C for TPA6130A2 Amplifier
  Wire.begin(TPA_SDA_PIN, TPA_SCL_PIN);
  Serial.println("I2C interface initialized for TPA6130A2.");
  setup_tpa6130a2();

  // Initialize I2S
  setup_i2s();

  // Initialize synth based on default type
  switch (DEFAULT_SYNTH_TYPE) {
    case SYNTH_SINE:
      currentSynth = new SineSynth();
      Serial.println("Initialized Sine Wave Synth");
      break;
    case SYNTH_SAW:
      currentSynth = new SawSynth();
      Serial.println("Initialized Sawtooth Wave Synth");
      break;
    case SYNTH_SQUARE:
      currentSynth = new SquareSynth();
      Serial.println("Initialized Square Wave Synth");
      break;
    case SYNTH_FM:
      currentSynth = new FMSynth();
      Serial.println("Initialized FM Synth");
      break;
    default:
      currentSynth = new SineSynth(); // Fallback to sine
      Serial.println("Invalid synth type, defaulting to Sine Wave");
      break;
  }
  currentSynth->setVolume(VOLUME_PERCENTAGE);

  Serial.println("Setup complete. Ready to play!");
}

// --- Main Loop ---
void loop() {
  // --- Keyboard Scanning ---
  bool keyStateChangedThisScan = false;
  for (int c = 0; c < NUM_COLS; c++) {
    digitalWrite(colPins[c], HIGH);
    delayMicroseconds(50); 

    for (int r = 0; r < NUM_ROWS; r++) {
      bool isPhysicallyPressed = (digitalRead(rowPins[r]) == HIGH);
      SwitchID_t currentSwitchEnum = physicalKeyToSwitchID[r][c];
      
      if (currentSwitchEnum != SW_INVALID) {
        int switchIntValue = static_cast<int>(currentSwitchEnum);
        bool previousState = currentSwitchIsPressed[switchIntValue];

        if (isPhysicallyPressed && !previousState) { // Newly pressed
          currentSwitchIsPressed[switchIntValue] = true;
          keyStateChangedThisScan = true;
          Note_t assignedNoteEnum = switchNoteAssignment[switchIntValue];
          
          if (assignedNoteEnum != NOTE_NONE && numActiveNotes < MAX_POLYPHONY) {
            // Add new note to active notes
            activeNotes[numActiveNotes].frequency = noteEnumToFrequencyMap[assignedNoteEnum];
            activeNotes[numActiveNotes].note = assignedNoteEnum;
            activeNotes[numActiveNotes].isActive = true;
            activeNotes[numActiveNotes].phase = 0.0f;
            activeNotes[numActiveNotes].modulatorPhase = 0.0f;
            numActiveNotes++;
            
            Serial.print("Note added: "); Serial.print(noteEnumToStringMap[assignedNoteEnum]);
            Serial.print(" ("); Serial.print(noteEnumToFrequencyMap[assignedNoteEnum], 2); 
            Serial.print(" Hz). Active notes: "); Serial.println(numActiveNotes);
          }
        } else if (!isPhysicallyPressed && previousState) { // Newly released
          currentSwitchIsPressed[switchIntValue] = false;
          keyStateChangedThisScan = true;
          Note_t releasedNote = switchNoteAssignment[switchIntValue];
          
          // Remove the released note from active notes
          for (int i = 0; i < numActiveNotes; i++) {
            if (activeNotes[i].note == releasedNote) {
              // Move the last active note to this position
              if (i < numActiveNotes - 1) {
                activeNotes[i] = activeNotes[numActiveNotes - 1];
              }
              numActiveNotes--;
              Serial.print("Note removed: "); Serial.print(noteEnumToStringMap[releasedNote]);
              Serial.print(". Active notes: "); Serial.println(numActiveNotes);
              break;
            }
          }
        }
      }
    }
    digitalWrite(colPins[c], LOW); 
  }

  // --- Audio Generation & Output ---
  for (int i = 0; i < I2S_BUFFER_SIZE * 2; i += 2) {
    float sample_float = 0.0f;
    
    // Generate samples for all active notes and sum them
    for (int note = 0; note < numActiveNotes; note++) {
      currentSynth->setFrequency(activeNotes[note].frequency);
      
      // Update phase for this note
      activeNotes[note].phase += (TWO_PI * activeNotes[note].frequency) / SAMPLE_RATE;
      if (activeNotes[note].phase >= TWO_PI) {
        activeNotes[note].phase -= TWO_PI;
      }
      
      // Generate sample for this note
      sample_float += (currentSynth->generateSample(activeNotes[note].phase, activeNotes[note].modulatorPhase)) / float(numActiveNotes);
    }
    
    // // Apply dynamic scaling based on number of active notes
    // if (numActiveNotes > 0) {
    //   // Scale factor decreases as more notes are played
    //   float scaleFactor = 1.0f / sqrtf(numActiveNotes);
    //   sample_float *= scaleFactor;
    // }
    
    // Apply volume and convert to 16-bit
    sample_float *= VOLUME_PERCENTAGE * MAX_AMPLITUDE * 0.5f;
    
    // Soft clipping to prevent harsh distortion
    if (sample_float > MAX_AMPLITUDE) {
      sample_float = MAX_AMPLITUDE - (MAX_AMPLITUDE - sample_float) * 0.1f;
    } else if (sample_float < -MAX_AMPLITUDE) {
      sample_float = -MAX_AMPLITUDE + (MAX_AMPLITUDE + sample_float) * 0.1f;
    }
    
    int16_t sample_int = (int16_t)sample_float;
    i2s_buffer[i] = sample_int;     // Left channel
    i2s_buffer[i + 1] = sample_int; // Right channel (mono sound on stereo)
  }

  size_t bytes_written = 0;
  esp_err_t result = i2s_write(I2S_NUM_0, i2s_buffer, sizeof(i2s_buffer), &bytes_written, portMAX_DELAY);
  if (result != ESP_OK) {
    Serial.print("I2S Write Error: "); Serial.println(esp_err_to_name(result));
  }
}

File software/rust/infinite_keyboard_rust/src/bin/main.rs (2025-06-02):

#![no_std]
#![no_main]

use esp_hal::{
    clock::CpuClock,
    delay::Delay,
    gpio::{Level, Output, OutputConfig},
};
use esp_println::println;
use esp_backtrace as _;
use embedded_hal::delay::DelayNs;

#[panic_handler]
fn panic(info: &core::panic::PanicInfo) -> ! {
    println!("Panic occurred: {:?}", info);
    loop {}
}

#[esp_hal::main]
fn main() -> ! {
    let config = esp_hal::Config::default().with_cpu_clock(CpuClock::max());
    let peripherals = esp_hal::init(config);

    // Create delay instance
    let mut delay = Delay::new();

    // Initialize LED pin (GPIO10)
    let mut led = Output::new(peripherals.GPIO10, Level::Low, OutputConfig::default());

    println!("🚀 ESP32-S3 LED Blinker");
    println!("=====================");
    println!("Hardware initialized successfully!");
    println!("CPU Clock: {:?}", CpuClock::max());
    println!("Chip model: ESP32-S3");

    let mut counter = 0u32;

    loop {
        // Toggle LED
        led.toggle();
        
        // Print status every 10 iterations
        if counter % 10 == 0 {
            println!("💡 LED blinked {} times", counter);
        }
        
        counter += 1;
        delay.delay_ms(500u32); // 500ms delay
    }
}

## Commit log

2025-05-09 Initial commit: Project setup with README and .gitignore
    [infinite_keyboard.kicad_pcb, infinite_keyboard.kicad_sch]
2025-05-09 PCB routing
    [freerouting.dsn, infinite_keyboard.kicad_pcb, infinite_keyboard.kicad_sch]
2025-05-12 Lots of updates
    [freerouting.dsn, infinite_keyboard.kicad_pcb, infinite_keyboard.kicad_sch]
2025-05-29 Misc changes
    [infinite_keyboard.kicad_pcb, infinite_keyboard.kicad_sch]
2025-05-29 Player updates
    [infinite_keyboard.kicad_sch]
